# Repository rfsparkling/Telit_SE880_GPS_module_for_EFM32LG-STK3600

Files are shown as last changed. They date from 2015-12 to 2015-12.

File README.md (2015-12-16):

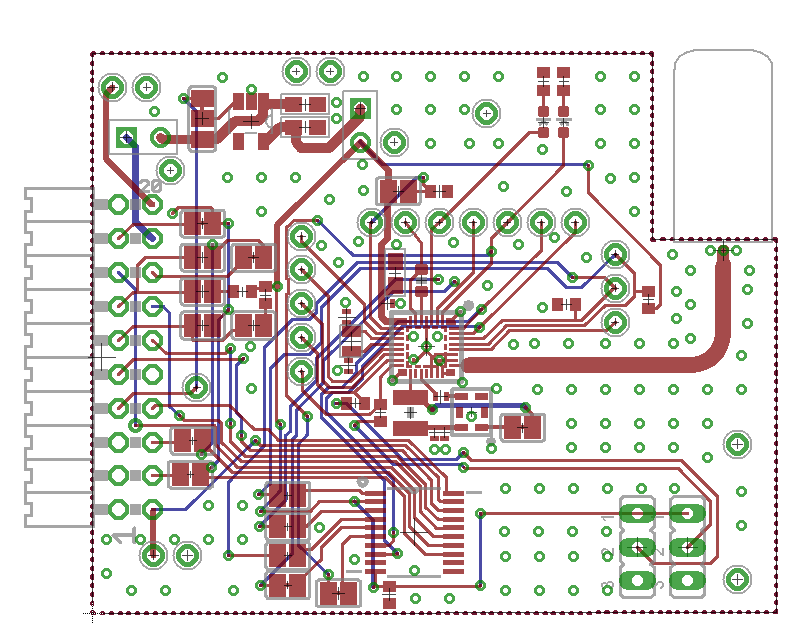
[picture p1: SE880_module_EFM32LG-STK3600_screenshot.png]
layout preview


This is my evaluation board for interfacing Telit SE880 GPS chip module with EFM32LG-STK3600 EFM32 Leopard Gecko Starter Kit.

I had lot of trouble during the SE880 chip module manufacturing, forget hot air blower! This is a 3D chip module with embedded parts, like capacitors, resistors, etc.
You need to follow the exact heat profile provided by Telit in tha datasheet. So using an SMT heat oven is highly recommended! 

My PCB is assembled (by professional contract manufacturer) and I confirm: it works! The parts are correct.

I have assambled PCBs to sell, please contact me about the details!

Validated Eagle Parts in this project:
Telit SE880
http://www.telit.com/products/product-service-selector/product-service-selector/show/product/jupiter-se880/

EFM32LG-STK3600 interface connector, pinhead connector
https://www.silabs.com/products/mcu/lowpower/Pages/efm32lg-stk3600.aspx

TI TXS0108E 
8-Bit Bidirectional Voltage-Level Shifter For Open-Drain And Push-Pull Application
http://www.ti.com/product/txs0108e

TI LP5907
250mA, Ultra-Low Noise Low-Dropout Regulator
http://www.ti.com/product/LP5907

AVX / Kyocera
TCXO Oscillators 16.369MHz 1.8Volts 2.5mmx2mm Sine Wave
http://www.mouser.co.uk/Search/Refine.aspx?Keyword=581-KT2520F16ACW18T

Abracon 
ABS06-32.768KHZ-T XTAL
http://www.digikey.com/product-detail/en/ABS06-32.768KHZ-T/535-10104-1-ND/2089921

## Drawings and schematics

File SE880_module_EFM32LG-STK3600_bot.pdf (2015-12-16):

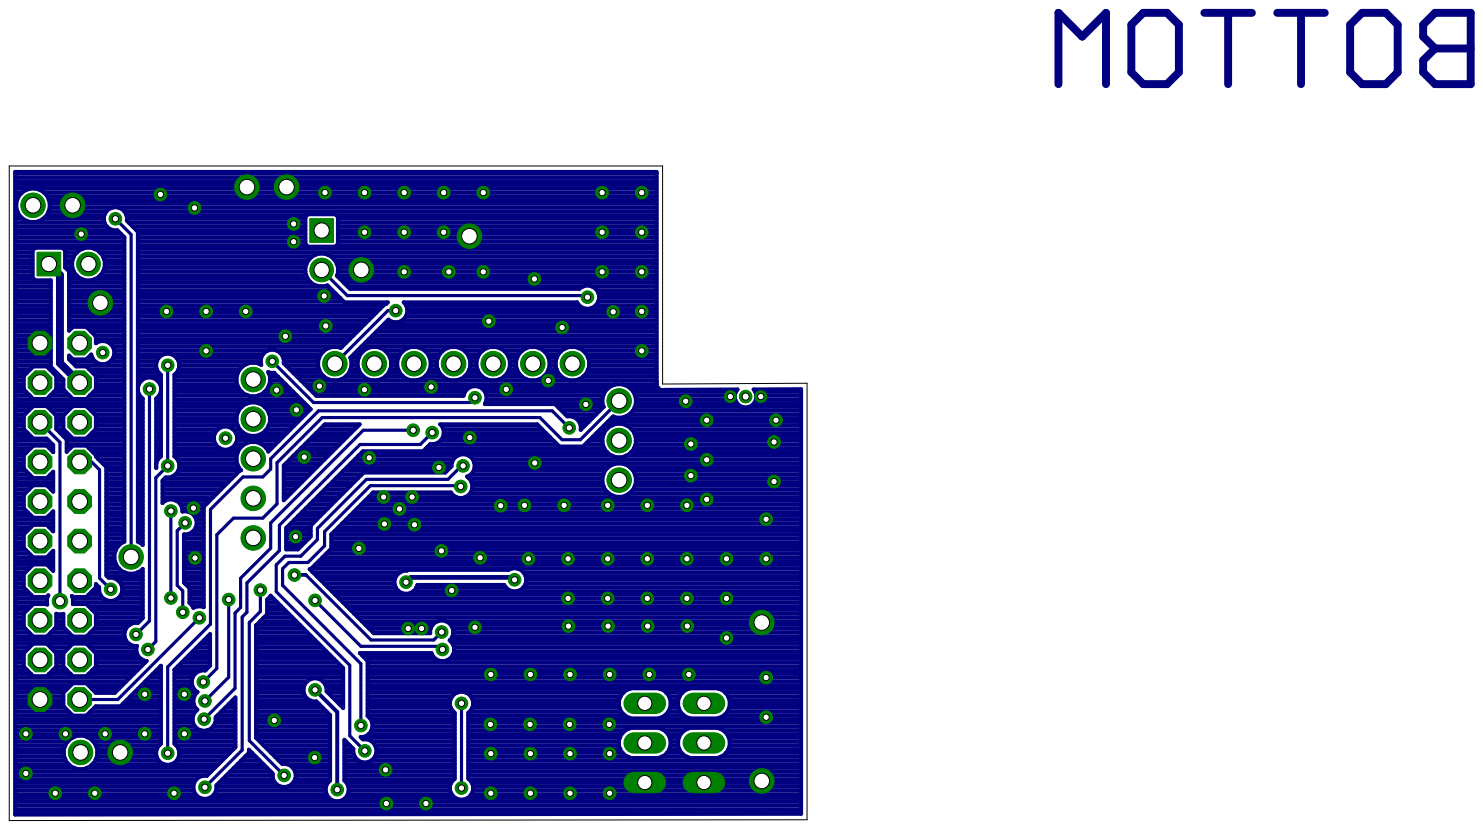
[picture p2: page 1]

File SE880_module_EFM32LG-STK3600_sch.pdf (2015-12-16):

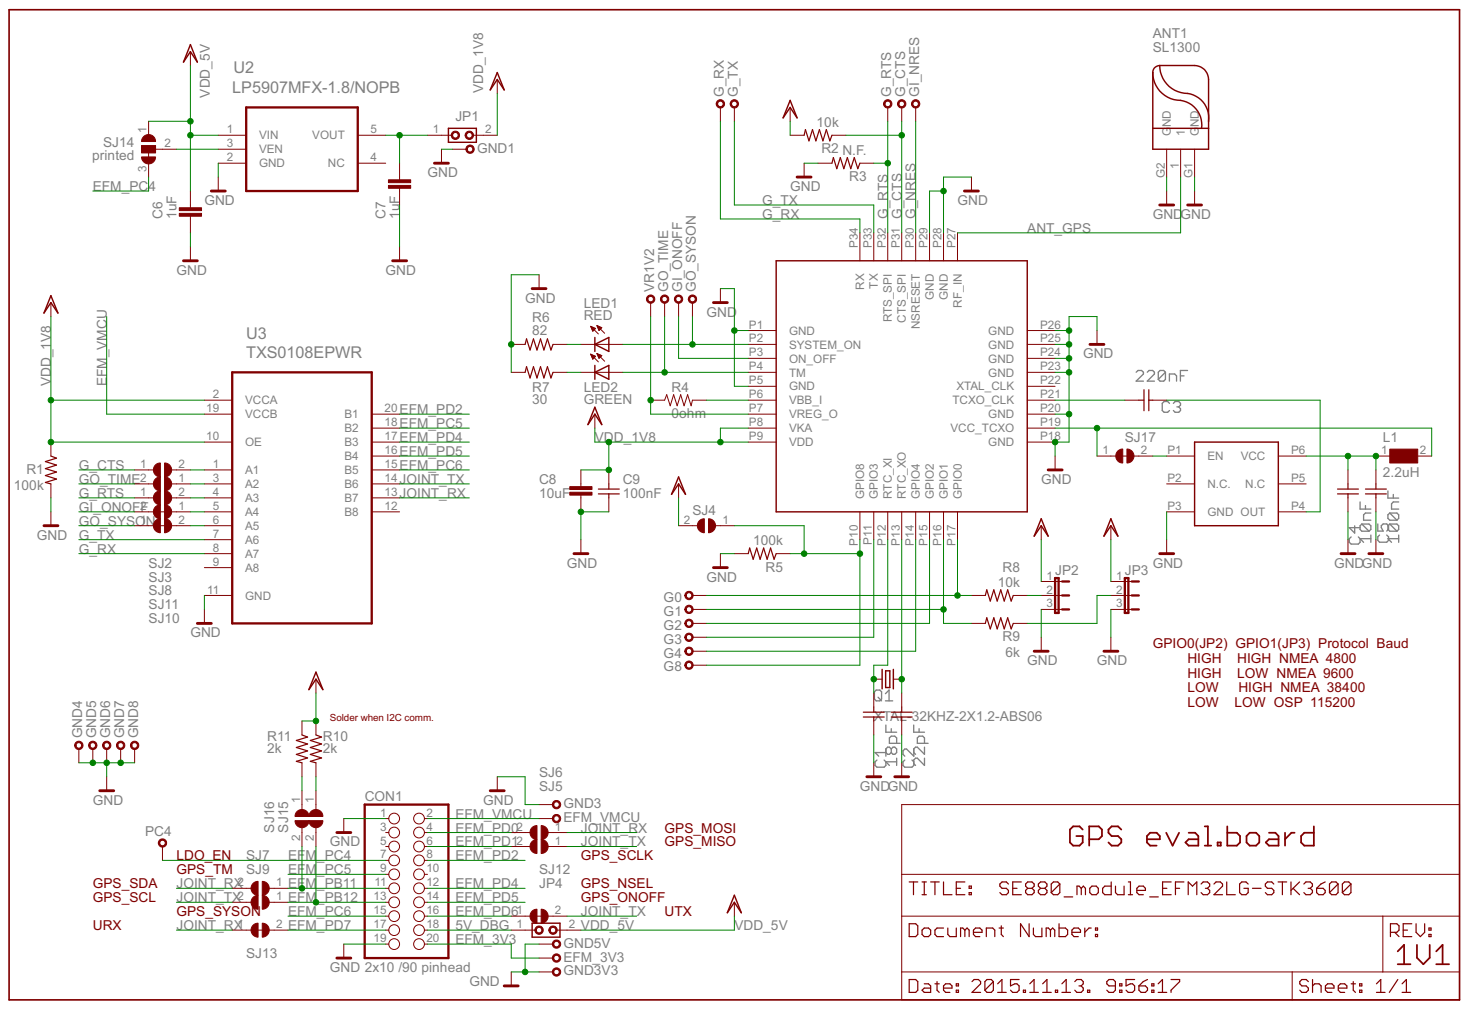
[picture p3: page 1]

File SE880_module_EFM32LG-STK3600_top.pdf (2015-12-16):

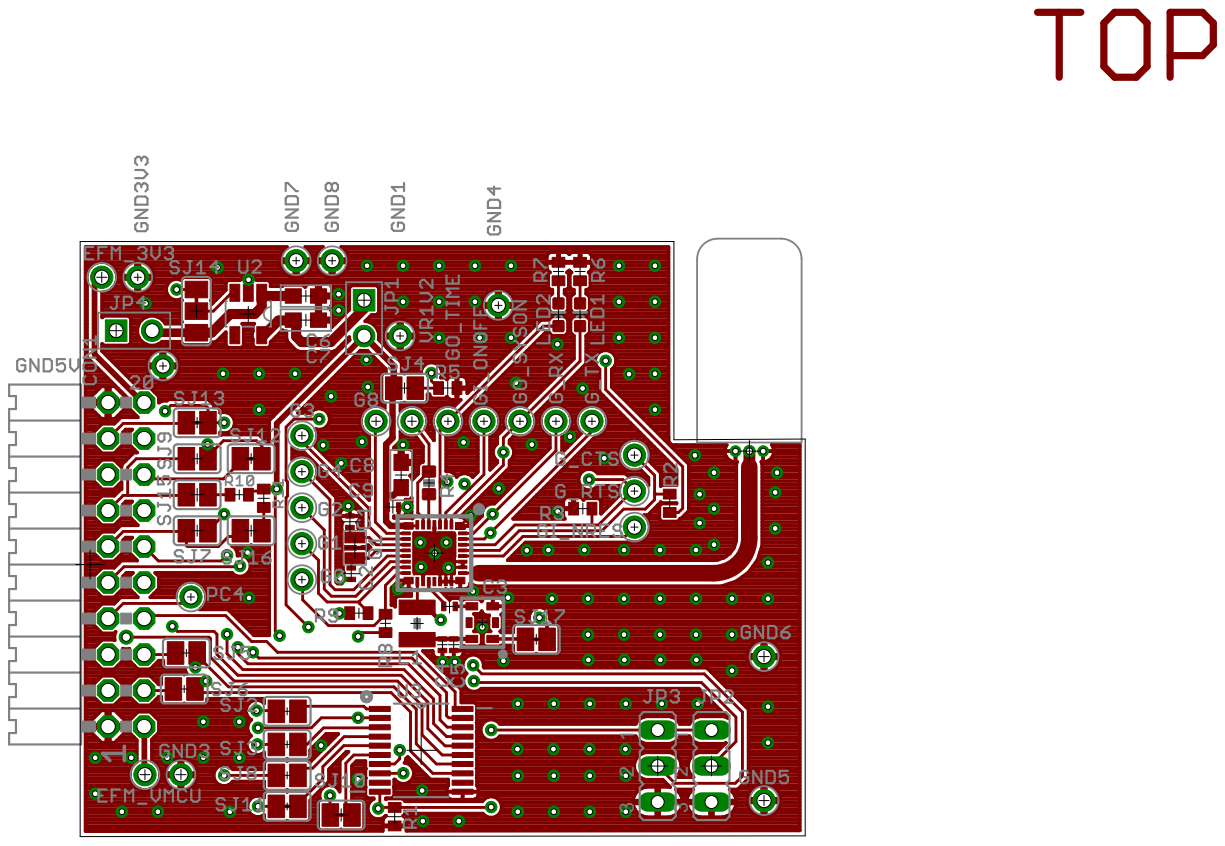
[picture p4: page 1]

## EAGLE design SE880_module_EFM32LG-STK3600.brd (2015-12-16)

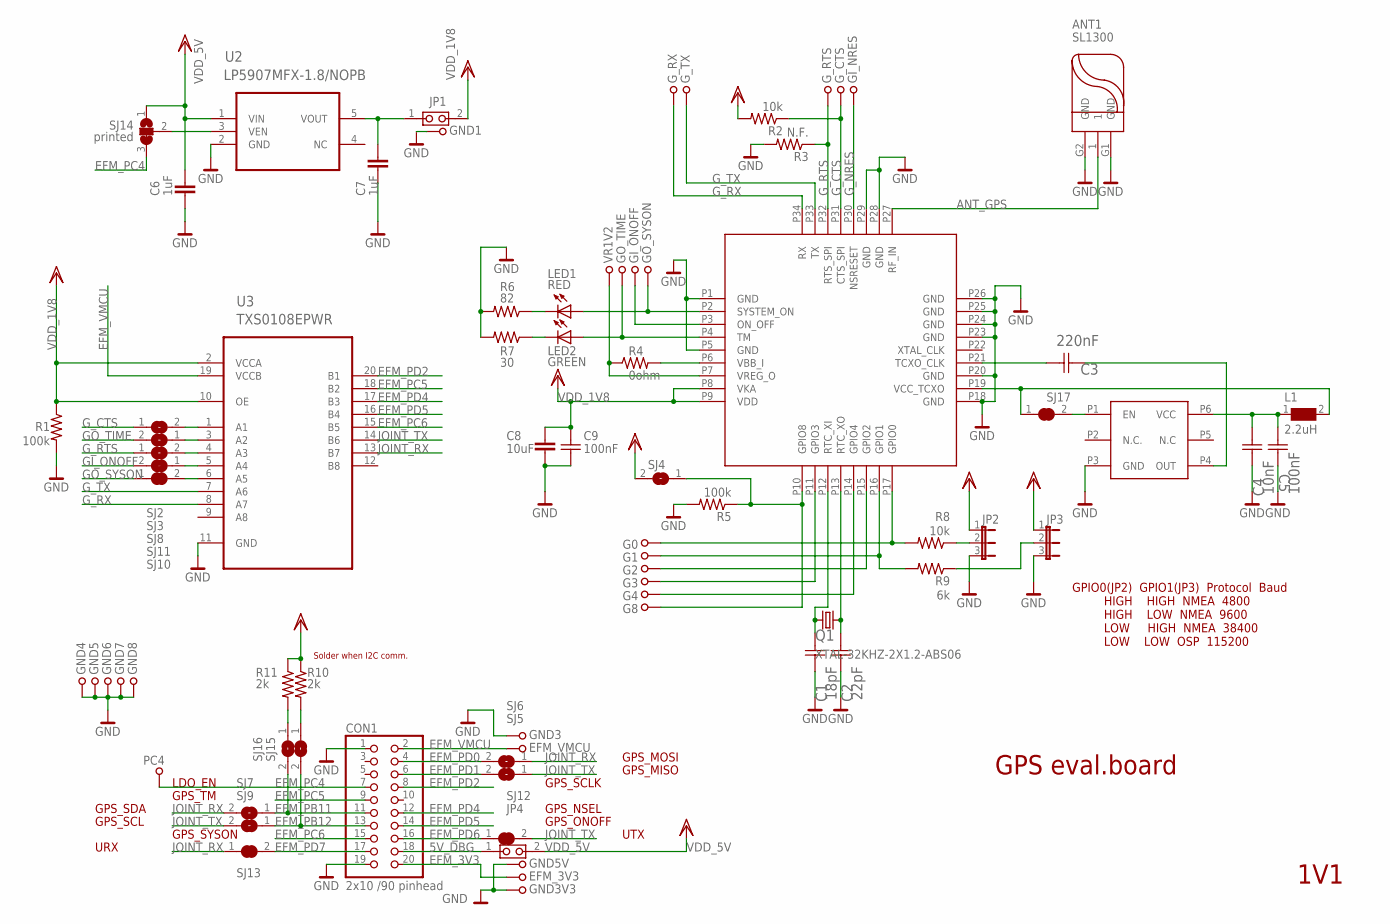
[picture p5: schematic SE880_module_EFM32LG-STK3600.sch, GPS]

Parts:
ANT1: SL1300
C1: 18pF; CAPC1005X60N
C2: 22pF; CAPC1005X60N
C3: 220nF; CAPC1005X60N
C4: 10nF; CAPC1005X60N
C5, C9: 100nF; CAPC1005X60N
C6, C7: 1uF; 0603
C8: 10uF; 0603
CON1: 2x10 /90 pinhead; 2X10/90_FEMALE_EFM_MUTANT
EFM_3V3: TESTPOINT39MIL; TESTPOINT1,0
EFM_VMCU: TESTPOINT39MIL; TESTPOINT1,0
G0, G1, G2, G3, G4, G8: TESTPOINT39MIL; TESTPOINT1,0
GI_NRES: TESTPOINT39MIL; TESTPOINT1,0
GI_ONOFF: TESTPOINT39MIL; TESTPOINT1,0
GND1, GND3, GND3V3, GND4, GND5, GND5V, GND6, GND7, GND8: TESTPOINT39MIL; TESTPOINT1,0
GO_SYSON: TESTPOINT39MIL; TESTPOINT1,0
GO_TIME: TESTPOINT39MIL; TESTPOINT1,0
G_CTS: TESTPOINT39MIL; TESTPOINT1,0
G_RTS: TESTPOINT39MIL; TESTPOINT1,0
G_RX: TESTPOINT39MIL; TESTPOINT1,0
G_TX: TESTPOINT39MIL; TESTPOINT1,0
JP1, JP4: JUMPER2-A; PIN2-1R
JP2, JP3: jumper 2mm; JP2
L1: 2.2uH; WE-KI_1008_B
LED1: RED; LED-0603
LED2: GREEN; LED-0603
PC4: TESTPOINT39MIL; TESTPOINT1,0
Q1: XTAL-32KHZ-2X1.2-ABS06; CRYSTAL-SMD-2X1.2-ABS06
Q3: KT2520F16369ACW18TAN; TCXO_2.5X2MM
R1, R5: 100k; R0402
R2, R8: 10k; R0402
R3: N.F.; R0402
R4: 0ohm; 0603-RES
R6: 82; R0402
R7: 30; R0402
R9: 6k; R0402
R10, R11: 2k; R0402
SJ2, SJ3, SJ4, SJ5, SJ6, SJ7, SJ8, SJ9, SJ15, SJ16: printed; JUMPER_SMD_SJ
SJ10, SJ11, SJ12, SJ13, SJ17: printed; JUMPER_SMD_SJ_1
SJ14: printed; JUMPER_SMD_SJ2A
U1: Telit SE880 GPS receiver; LGA-34
U2: LP5907MFX-1.8/NOPB; SOT-23/5-NEW
U3: TXS0108EPWR; SOP65P640X120-20N
VR1V2: TESTPOINT39MIL; TESTPOINT1,0

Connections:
5V_DBG: CON1.18, JP4.1 (A)
ANT_GPS: ANT1.1, U1.P27 (RF_IN)
EFM_3V3: CON1.20, EFM_3V3.1
EFM_PB11: CON1.11, SJ7.1, SJ16.2
EFM_PB12: CON1.13, SJ9.1, SJ15.2
EFM_PC4: CON1.7, PC4.1, SJ14.3
EFM_PC5: CON1.9, U3.18 (B2)
EFM_PC6: CON1.15, U3.15 (B5)
EFM_PD0: CON1.4, SJ6.2
EFM_PD1: CON1.6, SJ5.2
EFM_PD2: CON1.8, U3.20 (B1)
EFM_PD4: CON1.12, U3.17 (B3)
EFM_PD5: CON1.14, U3.16 (B4)
EFM_PD6: CON1.16, SJ12.1
EFM_PD7: CON1.17, SJ13.2
EFM_VMCU: CON1.2, EFM_VMCU.1, U3.19 (VCCB)
GI_ONOFF: GI_ONOFF.1, SJ11.2, U1.P3 (ON_OFF)
GND: ANT1.G1 (GND), ANT1.G2 (GND), C1.2 (C2), C2.2 (C2), C4.2 (C2), C5.2 (C2), C6.1, C7.1, C8.1, C9.2 (C2), CON1.1, CON1.19, GND1.1, GND3.1, GND3V3.1, GND4.1, GND5.1, GND5V.1, GND6.1, GND7.1, GND8.1, JP2.3, JP3.3, Q3.P3 (GND), R1.2, R3.2, R5.2, R6.2, R7.2, U1.P1 (GND), U1.P5 (GND), U1.P18 (GND), U1.P20 (GND), U1.P23 (GND), U1.P24 (GND), U1.P25 (GND), U1.P26 (GND), U1.P28 (GND), U1.P29 (GND), U2.2 (GND), U3.11 (GND)
GO_SYSON: GO_SYSON.1, LED1.A, SJ10.1, U1.P2 (SYSTEM_ON)
GO_TIME: GO_TIME.1, LED2.A, SJ3.2, U1.P4 (TM)
G_CTS: G_CTS.1, R2.1, SJ2.1, U1.P31 (CTS_SPI)
G_NRES: GI_NRES.1, U1.P30 (NSRESET)
G_RTS: G_RTS.1, R3.1, SJ8.1, U1.P32 (RTS_SPI)
G_RX: G_RX.1, U1.P34 (RX), U3.8 (A7)
G_TX: G_TX.1, U1.P33 (TX), U3.7 (A6)
JOINT_RX: SJ6.1, SJ7.2, SJ13.1, U3.13 (B7)
JOINT_TX: SJ5.1, SJ9.2, SJ12.2, U3.14 (B6)
unnamed: C2.1 (C1), Q1.P$2 (2), U1.P13 (RTC_XO)
unnamed: C1.1 (C1), Q1.P$1 (1), U1.P12 (RTC_XI)
unnamed: C3.1 (C1), U1.P21 (TCXO_CLK)
unnamed: C3.2 (C2), Q3.P4 (OUT)
unnamed: C4.1 (C1), C5.1 (C1), L1.1, Q3.P6 (VCC)
unnamed: L1.2, SJ17.1, U1.P19 (VCC_TCXO)
unnamed: G3.1, U1.P11 (GPIO3)
unnamed: C7.2, JP1.1 (A), U2.5 (VOUT)
unnamed: G4.1, U1.P14 (GPIO4)
unnamed: G2.1, U1.P15 (GPIO2)
unnamed: G1.1, R9.2, U1.P16 (GPIO1)
unnamed: G0.1, R8.2, U1.P17 (GPIO0)
unnamed: SJ14.2, U2.3 (VEN)
unnamed: Q3.P1 (EN), SJ17.2
unnamed: R10.2, SJ15.1
unnamed: LED1.C, R6.1
unnamed: R11.2, SJ16.1
unnamed: SJ2.2, U3.1 (A1)
unnamed: R4.2, U1.P6 (VBB_I)
unnamed: R4.1, U1.P7 (VREG_O), VR1V2.1
unnamed: G8.1, R5.1, SJ4.1, U1.P10 (GPIO8)
unnamed: LED2.C, R7.1
unnamed: JP2.2, R8.1
unnamed: JP3.2, R9.1
unnamed: SJ3.1, U3.3 (A2)
unnamed: SJ8.2, U3.4 (A3)
unnamed: SJ11.1, U3.5 (A4)
unnamed: SJ10.2, U3.6 (A5)
VDD_1V8: C8.2, C9.1 (C1), JP1.2 (B), JP2.1, JP3.1, R1.1, R2.2, R10.1, R11.1, SJ4.2, U1.P8 (VKA), U1.P9 (VDD), U3.2 (VCCA), U3.10 (OE)
VDD_5V: C6.2, JP4.2 (B), SJ14.1, U2.1 (VIN)

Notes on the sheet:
GPS eval.board
1V1
GPIO0(JP2) GPIO1(JP3) Protocol Baud HIGH HIGH NMEA 4800 HIGH LOW NMEA 9600 LOW HIGH NMEA 38400 LOW LOW OSP 115200
Solder when I2C comm.
GPS_NSEL
GPS_ONOFF
GPS_SCLK
GPS_SYSON
GPS_SCL
GPS_SDA
GPS_TM
LDO_EN
UTX
URX
GPS_MOSI
GPS_MISO

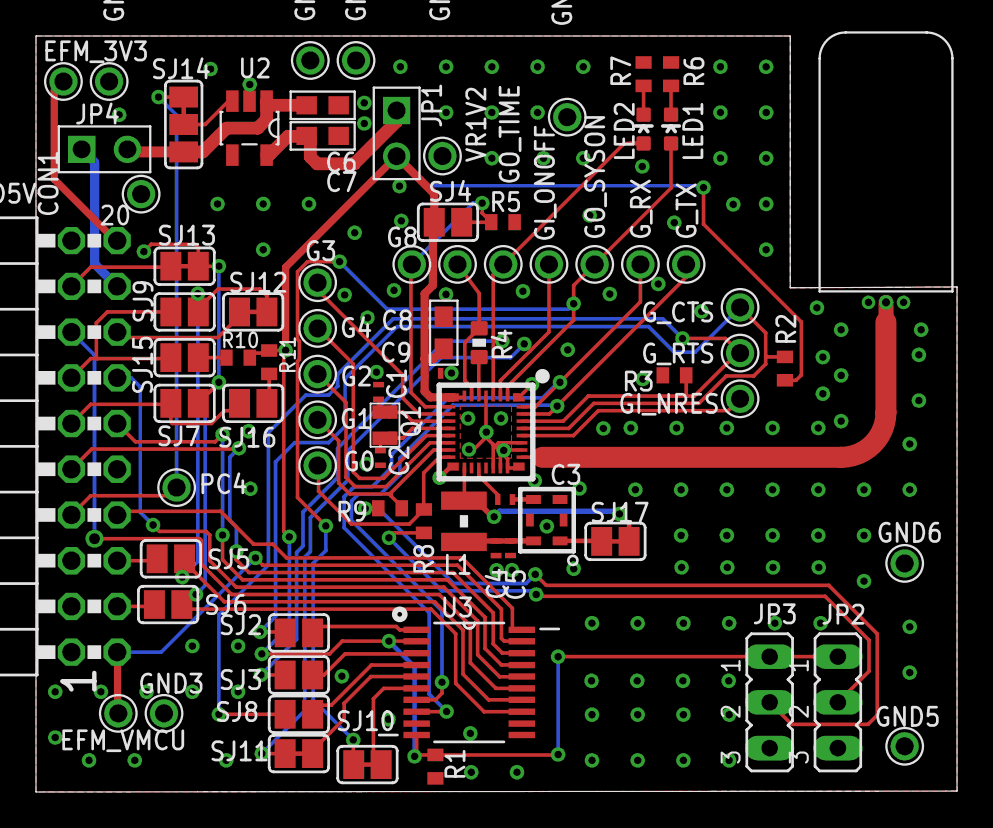
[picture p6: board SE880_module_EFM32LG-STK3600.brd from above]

Board: 2 copper layers, 51.2 x 42.0 mm, 77 parts (0 on the bottom side), 57 nets.

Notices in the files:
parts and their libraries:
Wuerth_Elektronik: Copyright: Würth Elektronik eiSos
